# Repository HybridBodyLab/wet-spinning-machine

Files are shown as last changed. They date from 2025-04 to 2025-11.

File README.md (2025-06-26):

# wet-spinning-machine

## Documentation Website
[hybridbodylab.github.io/open-wet-spinning](https://hybridbodylab.github.io/open-wet-spinning/)

## License

This project is open source and freely available under the following licenses:

- **Hardware designs** (PCBs, 3D-printable parts): [CERN-OHL-P v2.0](https://ohwr.org/project/cernohl/wikis/home)
- **Firmware**: [MIT License](https://opensource.org/licenses/MIT)
- **Documentation and media**: [Creative Commons Attribution 4.0 (CC BY 4.0)](https://creativecommons.org/licenses/by/4.0/)

You are free to use, modify, and distribute this project, provided that you give appropriate credit to the original author.

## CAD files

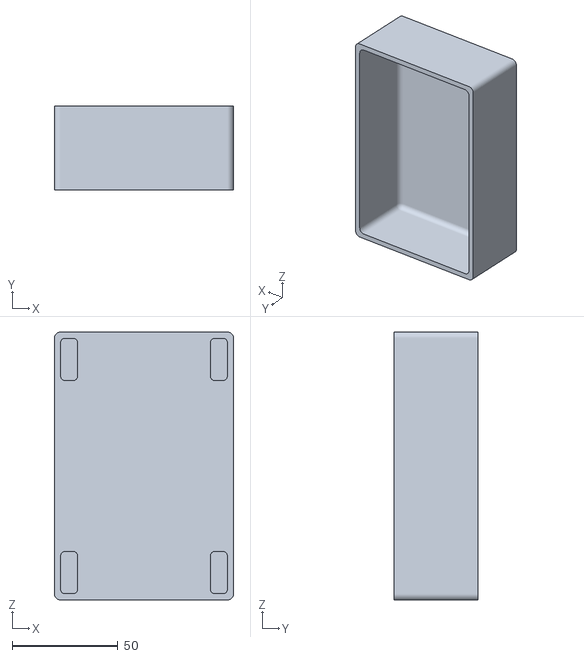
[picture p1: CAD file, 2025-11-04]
3d_models_stl/FDMWashBath.stl
85.0 x 40.0 x 127.0

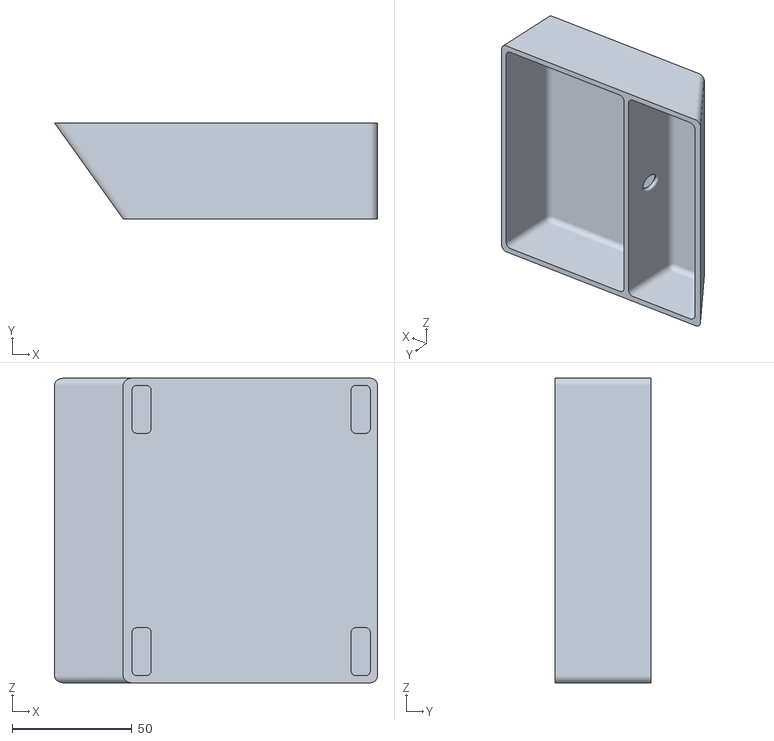
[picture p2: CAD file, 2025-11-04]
3d_models_stl/FDMCoagulationBath.stl
134.7 x 40.0 x 127.0

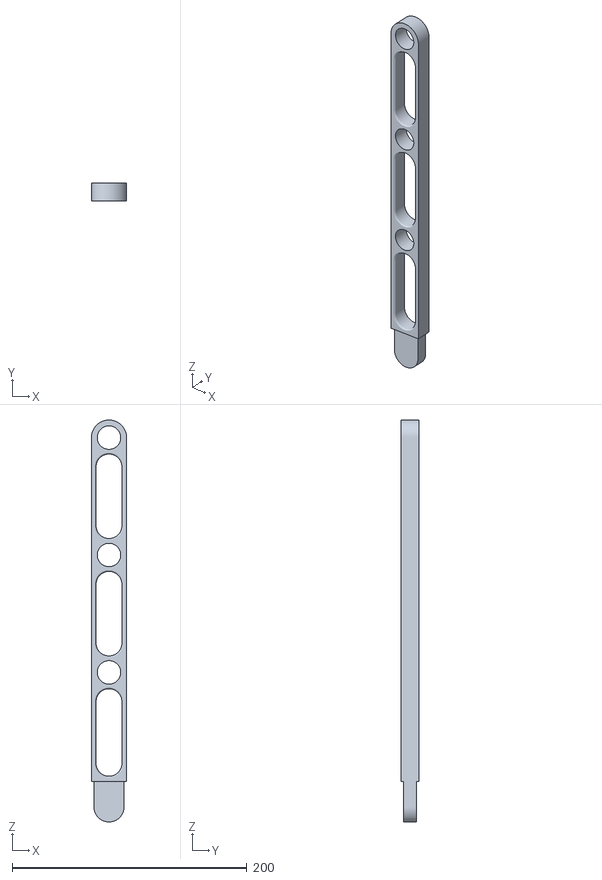
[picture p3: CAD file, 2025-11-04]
3d_models_stl/DryingStandRack.stl
30.0 x 15.0 x 342.5

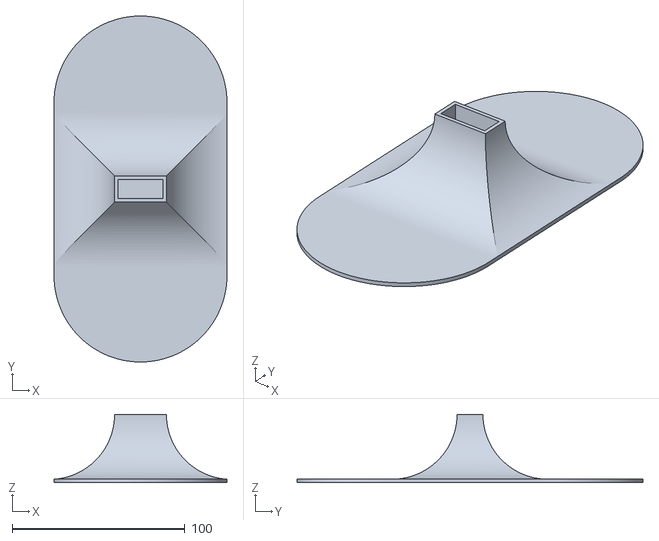
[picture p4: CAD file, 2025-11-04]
3d_models_stl/DryingStandBase.stl
100.0 x 200.0 x 39.5

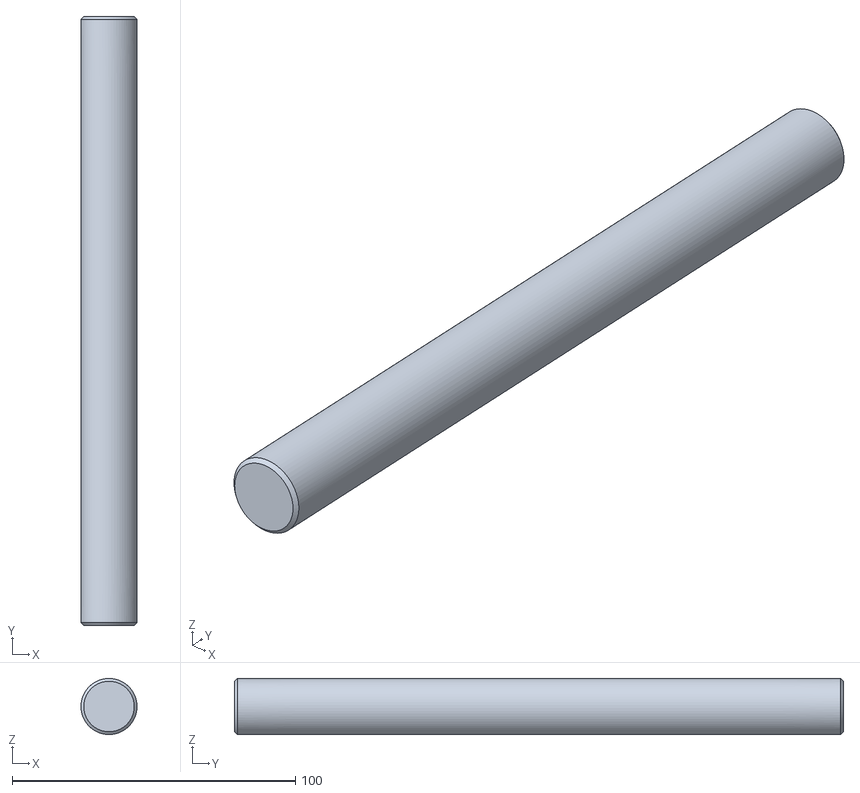
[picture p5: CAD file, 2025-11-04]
3d_models_stl/DryingStandRod.stl
19.8 x 215.0 x 19.8

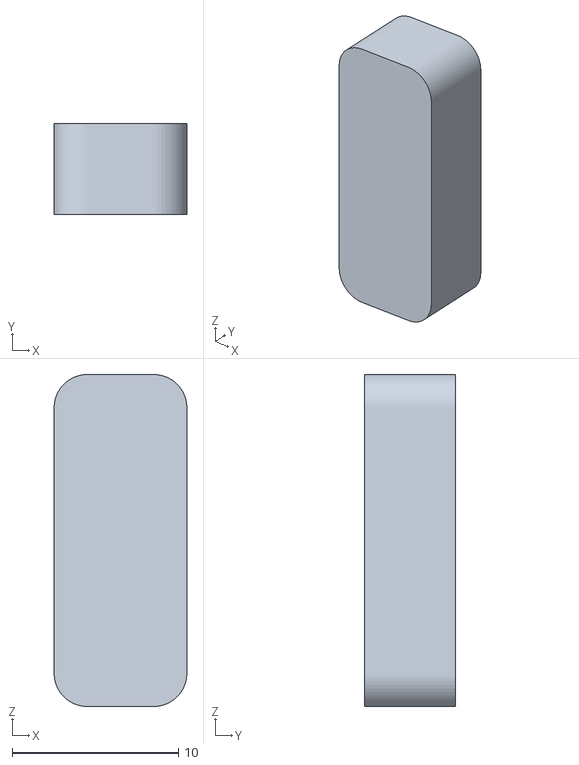
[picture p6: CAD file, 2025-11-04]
3d_models_stl/FDMBathStand.stl
8.00 x 5.50 x 20.0

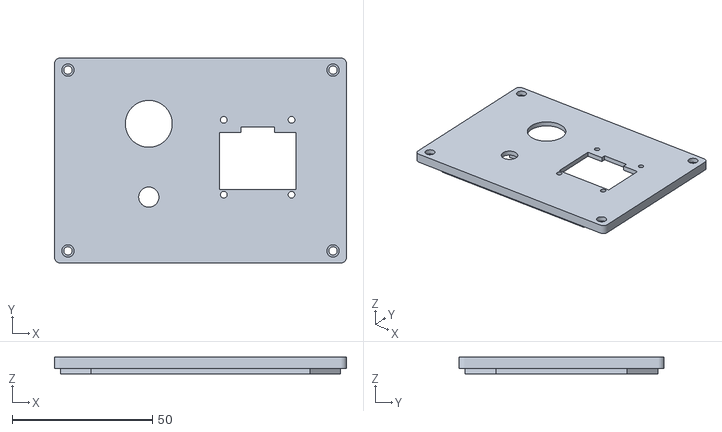
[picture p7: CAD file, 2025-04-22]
3d_models_stl/PCBLid.stl
104.0 x 73.0 x 6.00

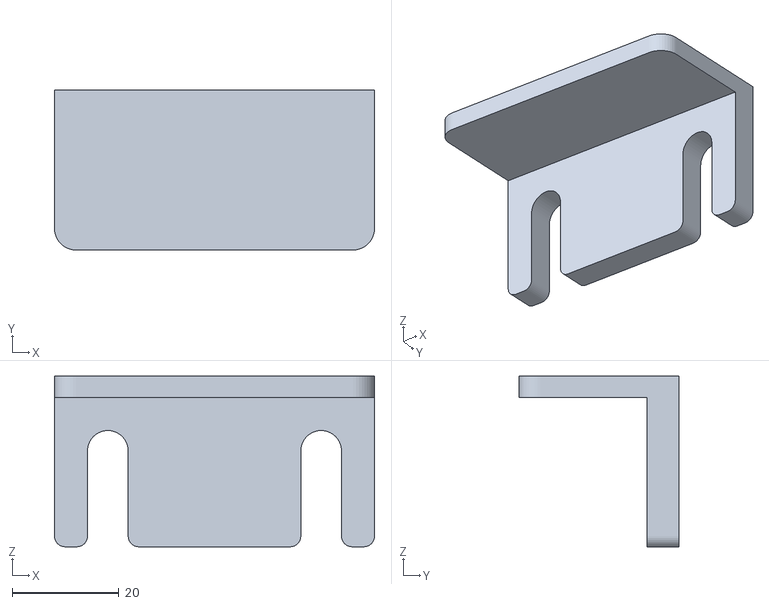
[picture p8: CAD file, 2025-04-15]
3d_models_stl/NarrowTankHolder.stl
60.0 x 30.0 x 32.0

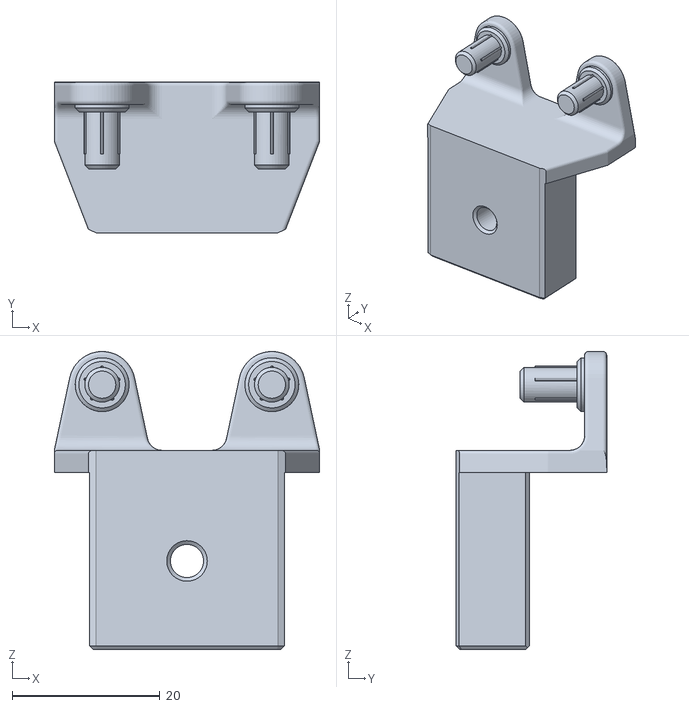
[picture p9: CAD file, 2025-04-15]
3d_models_stl/Axle.stl
36.0 x 20.4 x 40.4

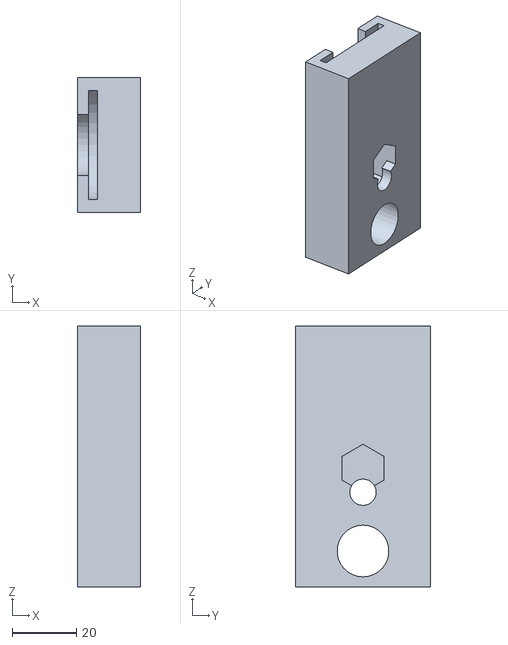
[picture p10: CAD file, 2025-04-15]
3d_models_stl/SyringeDisplacer.stl
19.6 x 42.0 x 81.2

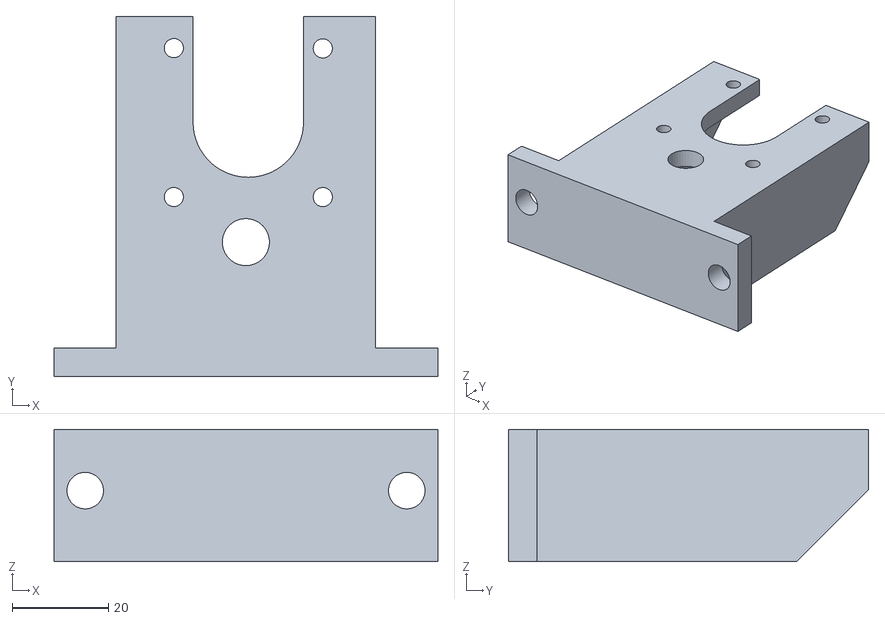
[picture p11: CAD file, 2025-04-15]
3d_models_stl/RollerMotorMount.stl
80.0 x 75.0 x 27.5

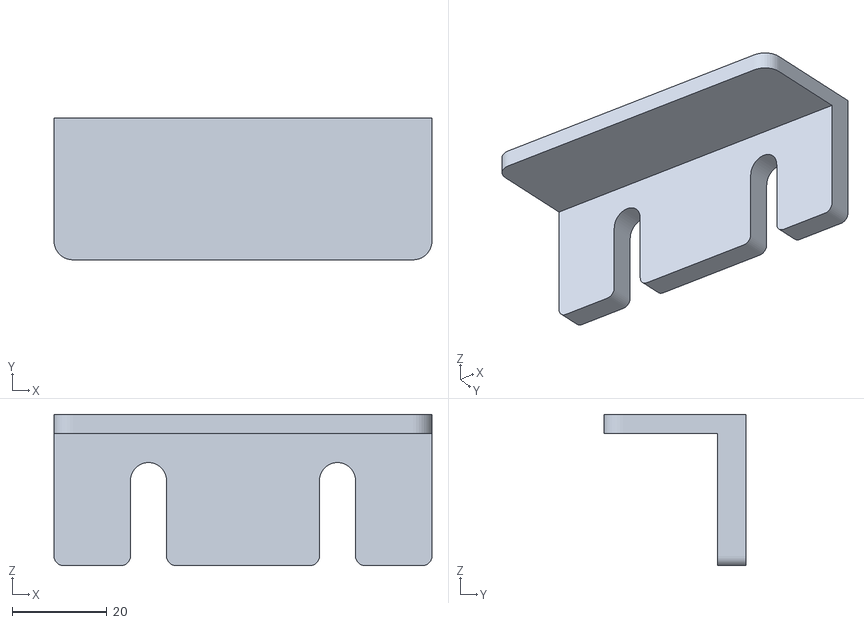
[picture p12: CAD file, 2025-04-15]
3d_models_stl/WideTankHolder.stl
80.0 x 30.0 x 32.0

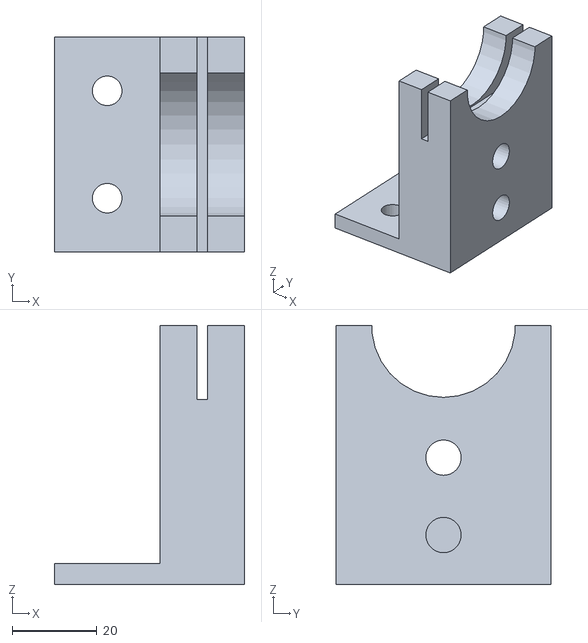
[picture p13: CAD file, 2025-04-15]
3d_models_stl/FlangeHolder.stl
45.0 x 50.8 x 61.2

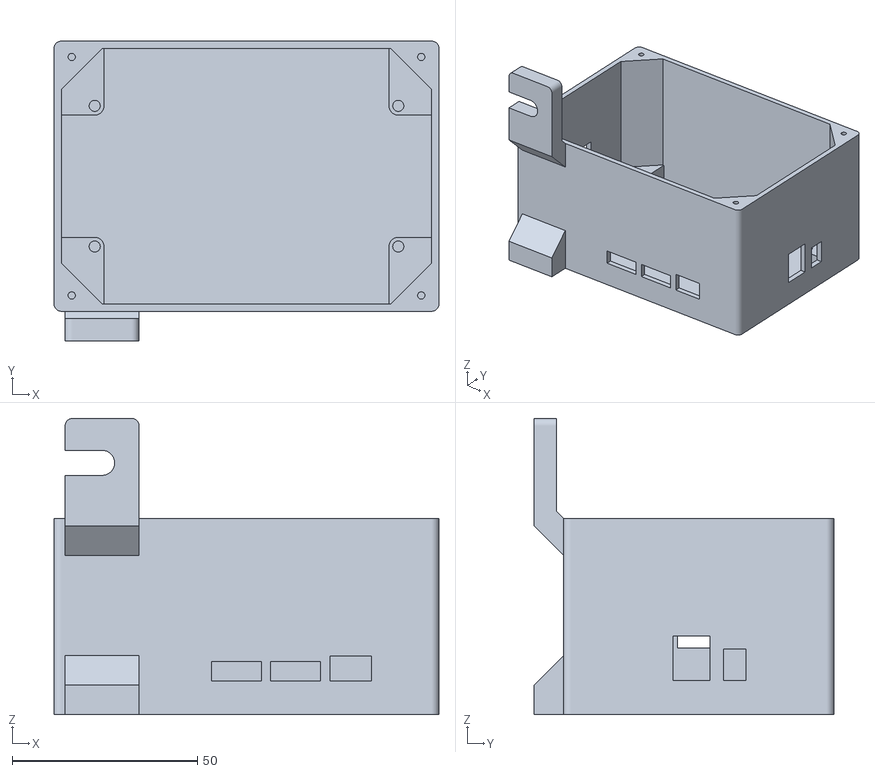
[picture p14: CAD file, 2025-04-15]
3d_models_stl/PCBBox.stl
104.0 x 81.0 x 80.0

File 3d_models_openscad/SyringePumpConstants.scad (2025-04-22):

/* === Project-universal Constants === */



//** syringe properties, change if using a different syringe **//
//units are mm
//used in syringe displacer
plungerDiameter = 34;
plungerThickness = 2.7;
plungerInnerDiameter = 19;

//used in flange holder
barrelDiameter = 32;
barrelSlotThickness = 2.5;
barrelSlotHeight = 35; //35

//used in syringe hub holder
hubDiameter = 10.4;
//** do not edit below **//



//Not all of these variables are used in this specific model,
//but the same variable set is used across all models in this project.

$fs = 0.1;

inch = 25.4; //for mm conversion

//width of base
baseSizeY = 2*inch;
centerY = baseSizeY / 2; //both axes go right down the middle of the base

//stepper motor
stepperZSize = 42;
stepperYSize = 42;

//608 bearing 
bearing608Height = 8.5;
bearing608Diameter = 22.5;

//height of holder for 80/20 screws
mountPlateHeight = 5;

//axis heights
threadedAxisHeight = stepperZSize/2 + mountPlateHeight + 4;
smoothAxisHeight = (threadedAxisHeight-6.6) / 2;
smoothRodRadius = 4.1; //original value: 4.2, previously changed to 4.05

syringeCenterHeight = threadedAxisHeight + bearing608Diameter/2 + 4 + barrelDiameter/2;

//fixes render oddities
floatCorrection = 0.001; 
floatCorrection2 = 2*floatCorrection; 

//8020 mounting plate
screwPlateSize = 25;	
screwRadius = 3.5;

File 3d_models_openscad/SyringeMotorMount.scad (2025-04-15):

include <syringePumpConstants.scad>

nema_17_mount();

module nema_17_mount()
{
	wall_thickness = 5;
	motor_width = 42;
	frame_width = motor_width + (wall_thickness + 1)*2;
	bolt = 4;
	height = 25;

	inch = 25.4;
	screwPlateSize = 15;	
	screwRadius = 3.25;
	
	//these are all the mount point holes.
	x1 = -wall_thickness;
	y1 = wall_thickness*2;
	x2 = frame_width+wall_thickness;
	y2 = wall_thickness*2;
	x3 = -wall_thickness;
	y3 = frame_width-wall_thickness*2;
	x4 = frame_width + wall_thickness;
	y4 = frame_width-wall_thickness*2;
    
    //these are for the smooth rod holder - Megan
    holderHeight = 10;
    holderThickness = 2;
    
    
    
	//center the whole thing in X
	translate([-frame_width/2, 0, 0])
	{

		//floor, with mounting holes for 80/20
			
		translate([0,-screwPlateSize,-wall_thickness]){
			difference(){
				cube(size=[frame_width,frame_width+2*screwPlateSize,wall_thickness]);
				
				translate([frame_width/2-inch/2, screwPlateSize/2, 0]){
					cylinder(h=wall_thickness, r=screwRadius);
				}
				translate([frame_width/2+inch/2, screwPlateSize/2, 0]){
					cylinder(h=wall_thickness, r=screwRadius);
				}
                
                //top screw plate added - Megan
                translate([frame_width/2+inch/2, frame_width+screwPlateSize*(3/2), 0]){
					cylinder(h=wall_thickness, r=screwRadius);
				}
                translate([frame_width/2-inch/2, frame_width+screwPlateSize*(3/2), 0]){
					cylinder(h=wall_thickness, r=screwRadius);
				}

			}
		}

		difference()
		{
			//build the main unit.
			union()
			{
				//structure
				cube([wall_thickness, frame_width, frame_width]); //front face
				cube([frame_width, wall_thickness, frame_width]); //left face
				translate([frame_width-wall_thickness, 0, 0])     //right face
					cube([wall_thickness, frame_width, frame_width]);

			}


			//front left mount hole
			echo(x1, y1);
			translate([x1, y1, 0])
			{
				cylinder(r=bolt/2, h=wall_thickness);
				translate([0,0,wall_thickness])
					cylinder(r=bolt, h=wall_thickness*2);
			}
			
			//front right mount hole
			echo(x2, y2);
			translate([x2, y2, 0])
			{
				cylinder(r=bolt/2, h=wall_thickness);
				translate([0,0,wall_thickness])
					cylinder(r=bolt, h=wall_thickness*2);			
			}
			
			//rear left mount hole
			echo(x3, y3);
			translate([x3, y3, 0])
			{
				cylinder(r=bolt/2, h=wall_thickness);
				translate([0,0,wall_thickness])
					cylinder(r=bolt, h=wall_thickness*2);
			}
			
			//rear right mount hole
			echo(x4, y4);
			translate([x4, y4, 0])
			{
				cylinder(r=bolt/2, h=wall_thickness);
				translate([0,0,wall_thickness])
					cylinder(r=bolt, h=wall_thickness*2);
			}
			
			//mount hole slits
			translate([frame_width + wall_thickness*1.5, frame_width-wall_thickness*2, wall_thickness/2])
				cube(size=[wall_thickness, 0.1, wall_thickness*3], center=true);
			translate([frame_width + wall_thickness*1.5, wall_thickness*2, wall_thickness/2])
				cube(size=[wall_thickness, 0.1, wall_thickness*3], center=true);
			translate([-wall_thickness*1.5, frame_width-wall_thickness*2, wall_thickness/2])
				cube(size=[wall_thickness, 0.1, wall_thickness*3], center=true);
			translate([-wall_thickness*1.5, wall_thickness*2, wall_thickness/2])
				cube(size=[wall_thickness, 0.1, wall_thickness*3], center=true);

			//nema 17 mount
			rotate([90, 0, 0])
			{
				translate([frame_width/2+0.5, height, -wall_thickness])
				{
					translate([15.5, 15.5, 0])
						cylinder(r=bolt/2, h=wall_thickness+1);
					translate([-15.5, 15.5, 0])
						cylinder(r=bolt/2, h=wall_thickness+1);
					translate([15.5, -15.5, 0])
						cylinder(r=bolt/2, h=wall_thickness+1);
					translate([-15.5, -15.5, 0])
						cylinder(r=bolt/2, h=wall_thickness+1);

					cylinder(r=11.5, h=wall_thickness+1);

					translate([-11.5, 0, 0])
						cube([23, frame_width, wall_thickness+1]);
				}
			}

			//back slant cutaway
			translate([0, 0, frame_width+wall_thickness])
				rotate([45, 0, 0])
					translate([-frame_width, 0, -frame_width*2])
						cube(size=[frame_width*4, frame_width*2, frame_width*4]);

			//front anti-warp circle
			translate([frame_width/2, wall_thickness*1.25, 0])
				rotate([90, 0, 0])
					cylinder(r=wall_thickness, h=wall_thickness*2);

			//middle anti-warp circle			
			translate([0, motor_width/2 + wall_thickness, 0])
				rotate([0, 90, 0])
					cylinder(r=wall_thickness, h=frame_width+1);

			//cutout / tidy up cubes.
			translate([wall_thickness, wall_thickness-0.1, -1])
				cube([frame_width-wall_thickness*2, frame_width-wall_thickness, motor_width*2]);
			translate([-frame_width/2,-frame_width/2, wall_thickness+motor_width])
				cube([frame_width*2, frame_width*2, frame_width]);
			translate([-frame_width/2, -frame_width/2,-frame_width])
				cube([frame_width*2, frame_width*2, frame_width]);
		}
	}
    
    
    // motion shaft holder - Megan
    translate([0, -(screwPlateSize - holderHeight), smoothAxisHeight - wall_thickness])rotate([90,0,0]){
        difference(){
            union(){
                cylinder(h = holderHeight, r = smoothRodRadius+holderThickness);
                translate([-(smoothRodRadius + holderThickness), -(smoothAxisHeight-wall_thickness), 0]){
                    cube([2*(smoothRodRadius + holderThickness), smoothAxisHeight-wall_thickness, holderHeight]);
                }
            }
            cylinder(h = holderHeight, r = smoothRodRadius);
        }
    }
           

}

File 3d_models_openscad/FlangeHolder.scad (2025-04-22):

include <syringePumpConstants.scad>

/* === Model-specific Constants === */

//cube containing rods and syringe barrel stop
mountXSize = 20;
mountZSize = syringeCenterHeight;


barrelSlotOffset = mountXSize/2 - barrelSlotThickness/2;


/* === Model === */

//main cube, holds the two axes
difference(){
	cube(size=[mountXSize,baseSizeY,mountZSize]);

	
	//bore hole for threaded rod
    //made bore hole same size as hole for smooth rod - Megan
	translate([-floatCorrection,centerY,threadedAxisHeight]){
		rotate(a=[0,90,0]){
			cylinder(h=mountXSize+floatCorrection2, r=smoothRodRadius+0.08);
		}
	}

	//hole for smooth rod (needs to fit fairly tight)
    //added a 5 unit thickness to hold the rod - Megan
	translate([-floatCorrection+5,centerY,smoothAxisHeight]){
		rotate(a=[0,90,0]){
			cylinder(h=mountXSize+floatCorrection2-5, r=smoothRodRadius+0.08);
		}
	}

	//hole for syringe barrel top to go in
	translate([barrelSlotOffset,centerY,syringeCenterHeight]){
		translate([0,-baseSizeY/2,-barrelSlotHeight/2]){
			cube(size=[barrelSlotThickness, baseSizeY, barrelSlotHeight]);
		}
	}	
	translate([-floatCorrection,centerY,syringeCenterHeight]){
		rotate(a=[0,90,0]){
			cylinder(h=mountXSize+floatCorrection2, r=plungerDiameter/2);
		}	
		translate([0,-plungerInnerDiameter/2,0]){
		}
	}	
	
}



// 80/20 screw plate
difference(){
	translate([-screwPlateSize,0,0]){
		cube(size=[screwPlateSize,baseSizeY,mountPlateHeight]);
	}

	translate([-screwPlateSize/2,baseSizeY/4,0]){
		cylinder(h=mountPlateHeight, r=screwRadius);
	}
	translate([-screwPlateSize/2,3*baseSizeY/4,0]){
		cylinder(h=mountPlateHeight, r=screwRadius);
	}

}

module bearing608(){
	cylinder(h=bearing608Height, r=bearing608Diameter/2);	
}

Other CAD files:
3d_models_stl/ShaftSleeve.stl
3d_models_stl/Roller.stl
3d_models_stl/WashBath.stl
3d_models_stl/Post.stl
3d_models_openscad/SyringeDisplacer.scad
3d_models_openscad/SyringeHubHolder.scad
3d_models_stl/CoagulationBath.stl
3d_models_stl/SyringeHubHolder.stl
3d_models_stl/SyringeMotorMount.stl

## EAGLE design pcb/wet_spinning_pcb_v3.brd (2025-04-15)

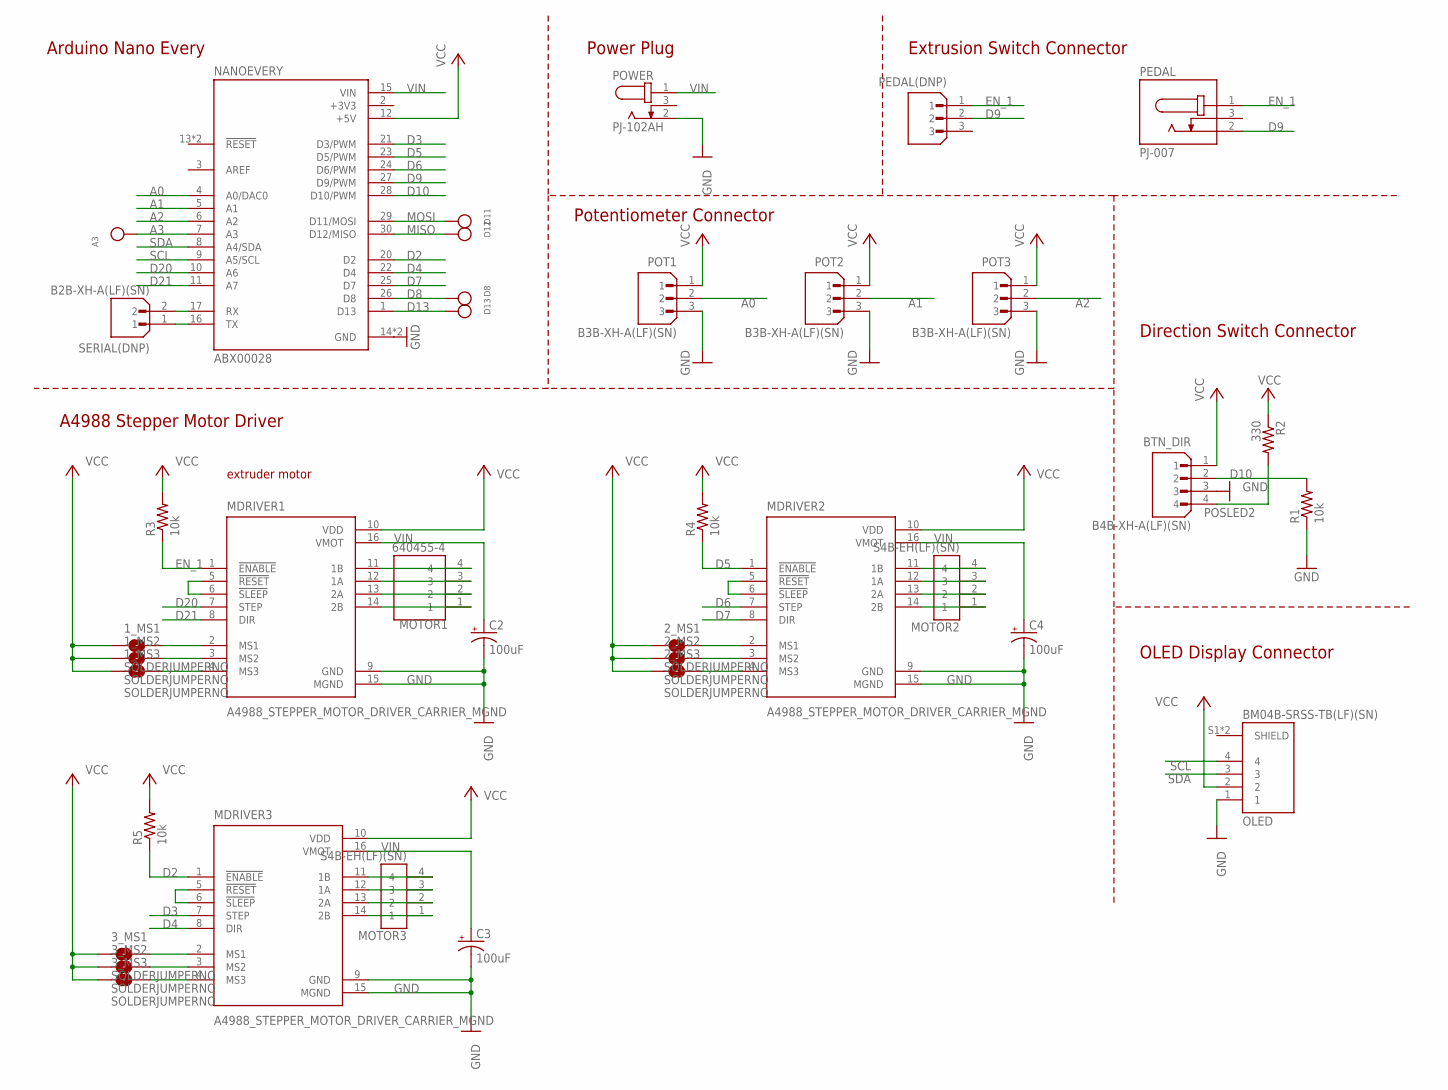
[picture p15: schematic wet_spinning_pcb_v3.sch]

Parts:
1_MS1, 1_MS2, 1_MS3, 2_MS1, 2_MS2, 2_MS3, 3_MS1, 3_MS2, 3_MS3: SOLDERJUMPERNO; SJ_2S-NO
A3: TESTPOINT0.1"; 1X01_ROUND
BTN_DIR: B4B-XH-A(LF)(SN); JST_B4B-XH-A(LF)(SN)
C2, C3, C4: 100uF; CPOL-RADIAL-2.5MM-6.5MM
D8, D11, D12, D13: TESTPOINT0.1"; 1X01_ROUND
MDRIVER1, MDRIVER2, MDRIVER3: A4988_STEPPER_MOTOR_DRIVER_CARRIER_MGND; MODULE_A4988_STEPPER_MOTOR_DRIVER_CARRIER
MOTOR1: 640455-4; TE_640455-4
MOTOR2, MOTOR3: S4B-EH(LF)(SN); JST_S4B-EH(LF)(SN)
NANOEVERY: ABX00028; MODULE_ABX00028
OLED: BM04B-SRSS-TB(LF)(SN); JST_BM04B-SRSS-TB(LF)(SN)
PEDAL: PJ-007; CUI_PJ-007
PEDAL(DNP): B3B-XH-A(LF)(SN); JST_B3B-XH-A(LF)(SN)
POT1, POT2, POT3: B3B-XH-A(LF)(SN); JST_B3B-XH-A(LF)(SN)
POWER: PJ-102AH; CUI_PJ-102AH
R1, R3, R4, R5: 10k; 0204/7
R2: 330; 0204/7
SERIAL(DNP): B2B-XH-A(LF)(SN); JST_B2B-XH-A(LF)(SN)

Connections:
+3V3: NANOEVERY.2 (+3V3)
A0: NANOEVERY.4 (A0/DAC0), POT1.2
A1: NANOEVERY.5 (A1), POT2.2
A2: NANOEVERY.6 (A2), POT3.2
A3: A3.1, NANOEVERY.7 (A3)
D2: MDRIVER3.1 (!ENABLE), NANOEVERY.20 (D2), R5.1
D3: MDRIVER3.7 (STEP), NANOEVERY.21 (D3/PWM)
D4: MDRIVER3.8 (DIR), NANOEVERY.22 (D4)
D5: MDRIVER2.1 (!ENABLE), NANOEVERY.23 (D5/PWM), R4.1
D6: MDRIVER2.7 (STEP), NANOEVERY.24 (D6/PWM)
D7: MDRIVER2.8 (DIR), NANOEVERY.25 (D7)
D8: D8.1, NANOEVERY.26 (D8)
D9: NANOEVERY.27 (D9/PWM), PEDAL.2, PEDAL(DNP).2
D10: BTN_DIR.2, NANOEVERY.28 (D10/PWM), R1.2
D13: D13.1, NANOEVERY.1 (D13)
D20: MDRIVER1.7 (STEP), NANOEVERY.10 (A6)
D21: MDRIVER1.8 (DIR), NANOEVERY.11 (A7)
EN_1: MDRIVER1.1 (!ENABLE), PEDAL.1, PEDAL(DNP).1, R3.1
GND: BTN_DIR.3, C2.2 (-), C3.2 (-), C4.2 (-), MDRIVER1.9 (GND), MDRIVER1.15 (MGND), MDRIVER2.9 (GND), MDRIVER2.15 (MGND), MDRIVER3.9 (GND), MDRIVER3.15 (MGND), NANOEVERY.14 (GND), NANOEVERY.19 (GND), OLED.1, POT1.3, POT2.3, POT3.3, POWER.2, R1.1
MISO: D12.1, NANOEVERY.30 (D12/MISO)
MOSI: D11.1, NANOEVERY.29 (D11/MOSI)
unnamed: MDRIVER1.12 (1A), MOTOR1.3
unnamed: MDRIVER1.11 (1B), MOTOR1.4
unnamed: MDRIVER3.14 (2B), MOTOR3.1
unnamed: MDRIVER3.13 (2A), MOTOR3.2
unnamed: MDRIVER1.5 (!RESET), MDRIVER1.6 (!SLEEP)
unnamed: MDRIVER3.5 (!RESET), MDRIVER3.6 (!SLEEP)
unnamed: MDRIVER2.5 (!RESET), MDRIVER2.6 (!SLEEP)
unnamed: 1_MS1.2, MDRIVER1.2 (MS1)
unnamed: MDRIVER1.14 (2B), MOTOR1.1
unnamed: MDRIVER1.13 (2A), MOTOR1.2
unnamed: 1_MS2.2, MDRIVER1.3 (MS2)
unnamed: 1_MS3.2, MDRIVER1.4 (MS3)
unnamed: MDRIVER3.12 (1A), MOTOR3.3
unnamed: MDRIVER3.11 (1B), MOTOR3.4
unnamed: MDRIVER2.14 (2B), MOTOR2.1
unnamed: MDRIVER2.13 (2A), MOTOR2.2
unnamed: MDRIVER2.12 (1A), MOTOR2.3
unnamed: MDRIVER2.11 (1B), MOTOR2.4
unnamed: NANOEVERY.16 (TX), SERIAL(DNP).1
unnamed: NANOEVERY.17 (RX), SERIAL(DNP).2
unnamed: 2_MS1.2, MDRIVER2.2 (MS1)
unnamed: 2_MS2.2, MDRIVER2.3 (MS2)
unnamed: 2_MS3.2, MDRIVER2.4 (MS3)
unnamed: 3_MS1.2, MDRIVER3.2 (MS1)
unnamed: 3_MS2.2, MDRIVER3.3 (MS2)
unnamed: 3_MS3.2, MDRIVER3.4 (MS3)
POSLED2: BTN_DIR.4, R2.2
SCL: NANOEVERY.9 (A5/SCL), OLED.4
SDA: NANOEVERY.8 (A4/SDA), OLED.3
VCC: 1_MS1.1, 1_MS2.1, 1_MS3.1, 2_MS1.1, 2_MS2.1, 2_MS3.1, 3_MS1.1, 3_MS2.1, 3_MS3.1, BTN_DIR.1, MDRIVER1.10 (VDD), MDRIVER2.10 (VDD), MDRIVER3.10 (VDD), NANOEVERY.12 (+5V), OLED.2, POT1.1, POT2.1, POT3.1, R2.1, R3.2, R4.2, R5.2
VIN: C2.1 (+), C3.1 (+), C4.1 (+), MDRIVER1.16 (VMOT), MDRIVER2.16 (VMOT), MDRIVER3.16 (VMOT), NANOEVERY.15 (VIN), POWER.1

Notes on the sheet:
Arduino Nano Every
A4988 Stepper Motor Driver
Extrusion Switch Connector
OLED Display Connector
Direction Switch Connector
Potentiometer Connector
Power Plug
extruder motor

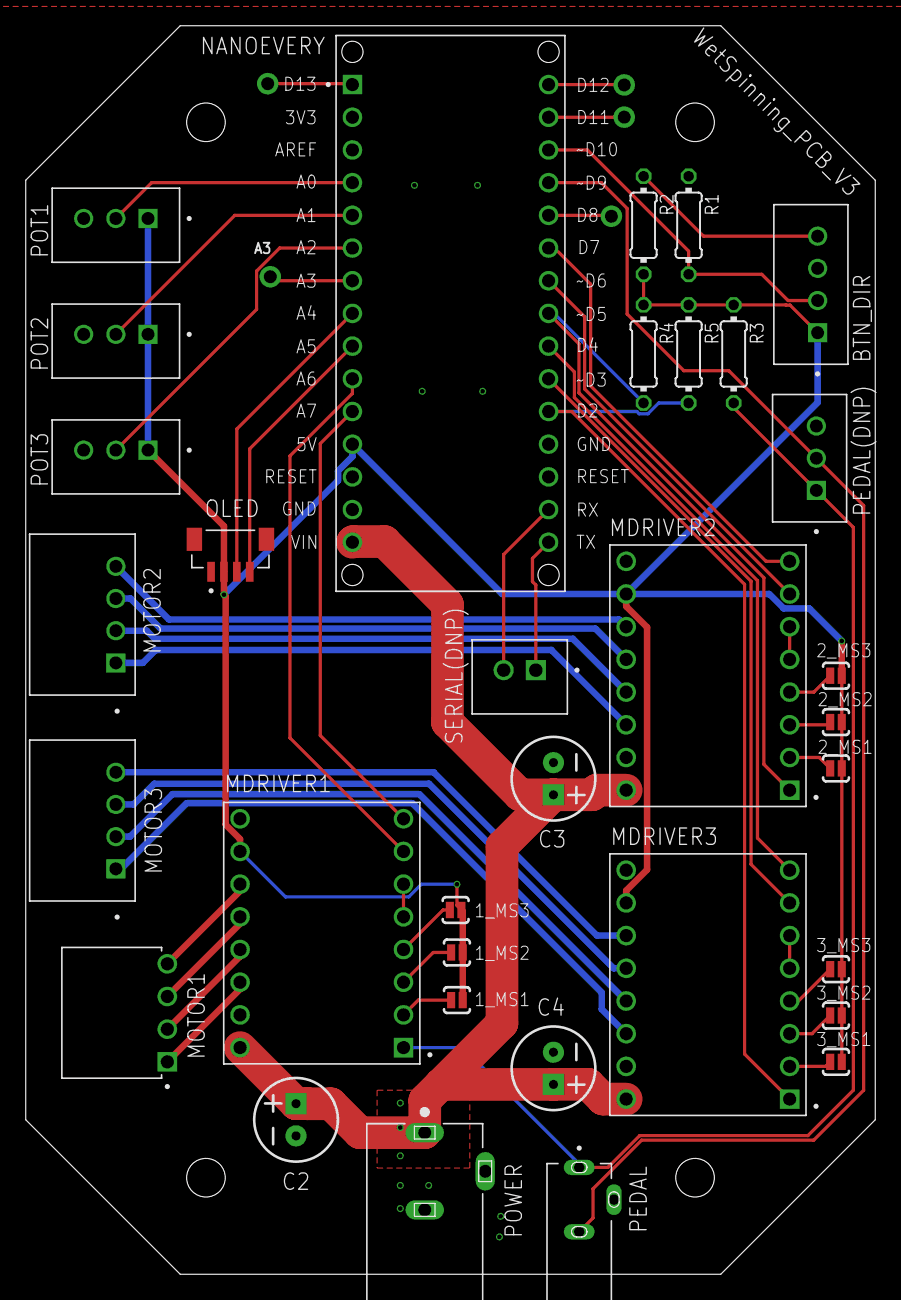
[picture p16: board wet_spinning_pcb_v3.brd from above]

Board: 2 copper layers, 66.0 x 97.0 mm, 38 parts (0 on the bottom side), 51 nets.

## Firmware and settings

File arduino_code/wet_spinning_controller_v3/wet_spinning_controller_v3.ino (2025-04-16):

/*
Motor driver - Motor connection
BLK-A-1A
GRN-C-1B
RED-B-2A
BLU-D-2B
*/

#include <SPI.h>
#include <Wire.h>
#include <Adafruit_GFX.h>
#include <Adafruit_SSD1306.h>

//define modes for different speed settings
#define MODE_RESET 0
#define MODE_REG 1
#define MODE_THERMO 2
#define MODE_CHARCOAL 3

/************SPEED SETTINGS*************/
//reset
#define EXTRUDER_DELAY_0 1
#define BOBBIN_DELAY_0 3

//regular
#define EXTRUDER_DELAY_1 8
#define BOBBIN_DELAY_1 3

//thermo
#define EXTRUDER_DELAY_2 12
#define BOBBIN_DELAY_2 5

//charcoal
#define EXTRUDER_DELAY_3 12
#define BOBBIN_DELAY_3 6
/***************************************/

#define SCREEN_WIDTH 128 // OLED display width, in pixels
#define SCREEN_HEIGHT 64 // OLED display height, in pixels
// Declaration for an SSD1306 display connected to I2C (SDA, SCL pins)
// The pins for I2C are defined by the Wire-library. 
// On an arduino nano every:       A4(SDA), A5(SCL)
#define OLED_RESET     -1 // Reset pin # (or -1 if sharing Arduino reset pin)
#define SCREEN_ADDRESS 0x3D ///< See datasheet for Address; 0x3D for 128x64, 0x3C for 128x32
Adafruit_SSD1306 display(SCREEN_WIDTH, SCREEN_HEIGHT, &Wire, OLED_RESET);

#define BAUD (9600)
// Motor 1, main extruder
#define EN_PIN 6    //driver enable pin, active low
#define DIR_PIN 10  //driver direction pin
#define STEP_PIN 9  //drive step pin

#define SW_PIN 3 //switch input for direction

//motor 2
#define EN_PIN_2 17    //driver enable pin, active low
#define DIR_PIN_2 21  //driver direction pin
#define STEP_PIN_2 20  //drive step pin

int current_mode = 1; //start with regular mode
int prev_mode = 1; 

int settingExtruderDelay, settingBobbinDelay;

bool prevDirection = 1; //1: forward direction, 0: backward direction
bool currentDirection = 1; ///1: forward direction, 0: backward direction

int prevExtrudeDelay; //extrusion speed delay
int tempExtrudeDelay;

unsigned long previousExtrudeMillis = 0;  // will store last extrusion stepper motor was updated
unsigned long extrudeInterval;  // interval at which to blink (milliseconds)
bool extrudeState = LOW; //the status of the step pin

unsigned long previousBobbinMillis = 0;  // will store last bobbin stepper motor was updated
unsigned long bobbinInterval;  // interval at which to blink (milliseconds)
bool bobbinState = LOW; //the status of the step pin

bool dir; //direction display flag
bool sp; //speed display flag
bool md; //mode display flag


void setup() {
  Serial.begin(BAUD);

  delay(2000);
  // SSD1306_SWITCHCAPVCC = generate display voltage from 3.3V internally
  display.setTextSize(2);             // 2:2 pixel scale
  display.setTextColor(SSD1306_WHITE);        // Draw white text
  if(!display.begin(SSD1306_SWITCHCAPVCC, SCREEN_ADDRESS)) {
    Serial.println(F("SSD1306 allocation failed"));
    for(;;); // Don't proceed, loop forever
  }
  display.clearDisplay();
  display.println("EcoThreads"); // forward
  display.print("V3");
  display.display();
  delay(1000);
  
  pinMode(EN_PIN, OUTPUT);      // Enable
  pinMode(STEP_PIN, OUTPUT);    // Step
  pinMode(DIR_PIN, OUTPUT);     // Dir
  pinMode(SW_PIN, INPUT);       // Direction switch
  digitalWrite(EN_PIN, LOW);    // Set Enable low

  pinMode(EN_PIN_2, OUTPUT);      // Enable
  pinMode(STEP_PIN_2, OUTPUT);    // Step
  pinMode(DIR_PIN_2, OUTPUT);     // Dir
  digitalWrite(EN_PIN_2, HIGH);    // Set Enable low
  digitalWrite(DIR_PIN_2,HIGH); //HIGH: collect, LOW: release

  currentDirection = digitalRead(SW_PIN); //read initial direction switch
  digitalWrite(DIR_PIN, currentDirection);  // Set Dir high, forward
  prevDirection = currentDirection;

  checkMode();
  prevExtrudeDelay = settingExtruderDelay; 
  tempExtrudeDelay = prevExtrudeDelay;
  extrudeInterval = (unsigned long)prevExtrudeDelay;
  drawText(tempExtrudeDelay, currentDirection);
}

void loop() {

  //check direction switch
  currentDirection = digitalRead(SW_PIN); //read initial direction switch
  dir = currentDirection != prevDirection; //update display flag
  if(dir){
    digitalWrite(DIR_PIN, currentDirection);  // Set Dir high, forward
    digitalWrite(EN_PIN_2, !currentDirection);
    prevDirection = currentDirection;
    //Serial.println("switch direction");
  }

  //check speed potentiometer
  checkMode();
  md = prev_mode != current_mode;
  sp = prevExtrudeDelay != settingExtruderDelay; //update display flag
  extrudeInterval = (unsigned long) (settingExtruderDelay);

  //drive the extrusion motor
  unsigned long currentMillis = millis();

  if (currentMillis - previousExtrudeMillis >= extrudeInterval) {
    // save the last time you blinked the LED
    previousExtrudeMillis = currentMillis;
    // if the LED is off turn it on and vice-versa:
    if (extrudeState == LOW) {
      extrudeState = HIGH;
    } else {
      extrudeState = LOW;
    }
    digitalWrite(STEP_PIN, extrudeState);
  }

  if (currentMillis - previousBobbinMillis >= bobbinInterval) {
    // save the last time you blinked the LED
    previousBobbinMillis = currentMillis;
    // if the LED is off turn it on and vice-versa:
    if (bobbinState == LOW) {
      bobbinState = HIGH;
    } else {
      bobbinState = LOW;
    }
    digitalWrite(STEP_PIN_2, bobbinState);
  }


  //update display
  if (md|| sp || dir) {
    tempExtrudeDelay = settingExtruderDelay;
    if(current_mode == MODE_RESET){
      digitalWrite(DIR_PIN_2,LOW); //HIGH: collect, LOW: release
    }else{
      digitalWrite(DIR_PIN_2,HIGH); //HIGH: collect, LOW: release
    }
    
    drawText(tempExtrudeDelay, currentDirection);
    if (sp) {
      prevExtrudeDelay = settingExtruderDelay;
    }
    if(md){
      prev_mode = current_mode;
    }
  }

}

// int speedUp() {
//   int potReading = analogRead(A0); // Reads the potentiometer
//   int newCustomSpeed = map(potReading, 0, 1023, 1,EXTRUDER_DELAY); // Convrests the read values of the potentiometer from 0 to 1023 into desireded delay values (300 to 4000)
//   if(potReading < 4){
//     newCustomSpeed = 1;
//   } //reduce floating value
  
//   if (potReading > 1015){
//     newCustomSpeed = EXTRUDER_DELAY;
//   } //reduce floating value
//   return newCustomSpeed;
// }

void drawText(int spd, int dir) {
  display.clearDisplay();

  display.setCursor(0,0);             // Start at top-left corner
  switch (current_mode) {
    case MODE_RESET: 
      display.println(F("RESET"));
      display.print(F("Speed:"));
      display.println(spd);
      break;
    case MODE_REG:
      display.println(F("REGULAR"));
      display.print(F("Speed:"));
      display.println(spd);
      break;
    case MODE_THERMO:
      display.println(F("THERMO"));
      display.print(F("Speed:"));
      display.println(spd);
      break;
    case MODE_CHARCOAL:
      display.println(F("CHARCOAL"));
      display.print(F("Speed:"));
      display.println(spd);
      break;
    default:
      break;
  }

  display.println("Direction:");

  if (dir == 1) {
    display.println("Forward"); // forward
  } else {
    display.println("Backward"); // backward
  }

  display.display();
}

void checkMode(){

  int potReading = analogRead(A0); // Reads the potentiometer
  //Serial.println(potReading);
  if(potReading < 140){
    current_mode = MODE_CHARCOAL;
    settingExtruderDelay = EXTRUDER_DELAY_3;
    bobbinInterval = BOBBIN_DELAY_3;
  }else if (potReading < 650){
    current_mode = MODE_THERMO;
    settingExtruderDelay = EXTRUDER_DELAY_2;
    bobbinInterval = BOBBIN_DELAY_2;

  }else if (potReading < 950){
    current_mode = MODE_REG;
    settingExtruderDelay = EXTRUDER_DELAY_1;
    bobbinInterval = BOBBIN_DELAY_1;

  }else{
    current_mode = MODE_RESET;
    settingExtruderDelay = EXTRUDER_DELAY_0;
    bobbinInterval = BOBBIN_DELAY_0;
  }
}

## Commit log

2025-04-15 added stl files and openscad files
    [AxleYoke.stl, CoagulationBath.stl, FlangeHolder.scad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]
2025-04-15 added openscad files
    [FlangeHolder.scad]
2025-04-15 added pcb design and arduino code
    [wet_spinning_pcb_v3.brd, wet_spinning_pcb_v3.sch]
2025-04-16 Updated arduino comments
2025-04-22 updated and renamed files
    [Axle.stl, FlangeHolder.scad, PCBLid.stl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]

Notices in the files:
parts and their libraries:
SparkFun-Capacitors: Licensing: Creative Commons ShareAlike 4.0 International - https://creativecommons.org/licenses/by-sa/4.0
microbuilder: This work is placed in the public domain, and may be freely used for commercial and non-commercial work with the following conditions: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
